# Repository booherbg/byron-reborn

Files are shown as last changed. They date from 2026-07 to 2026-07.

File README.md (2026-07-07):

# Byron Reborn

A fully 3D-printed, genuinely leak-proof replacement lid for the **Contigo Byron 2.0** 16oz travel mug (SnapSeal style) — because the OEM lid warps eventually, and the mug deserves better.

**Status:** toolkit built (measuring kit + thread test rings in `stl/`). Waiting on mug
measurements — **see [NEXT-STEPS.md](NEXT-STEPS.md) to pick this up** (30-min human
checklist + a paste-ready LLM resume prompt).

## The idea

- **Parametric OpenSCAD** (BOSL2 threads) — every mug measurement is a variable in `scad/params.scad`
- **Main seal, two variants:** a gland for the OEM Byron silicone grommet (daily driver), and a 100%-printed double-lip skirt (the experiment)
- **Snap lever spout:** an over-center lever cams a hollow tapered plug into a printed taper seat — Luer-fitting physics, no o-rings
- **Printed metrology:** no calipers? The printer bootstraps its own measuring kit (step-cone bore gauge, thread pitch comb, grommet slot card)
- **PETG only** — coffee is hotter than PLA's glass transition; that heat creep is what killed the original lid

Full design: [docs/superpowers/specs/2026-07-07-byron-lid-design.md](docs/superpowers/specs/2026-07-07-byron-lid-design.md)

## Hardware

- Contigo Byron **2.0** 16oz (the newer AUTOSEAL tops use a different interface — this won't fit those)
- Bambu Lab H2D, PETG

## Safety notes

Hobby part, not NSF-certified. Hand-wash only, reprint periodically, PETG throughout.

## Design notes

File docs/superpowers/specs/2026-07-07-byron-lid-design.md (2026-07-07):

# Byron Reborn — Printed Leak-Proof Replacement Lid for Contigo Byron 2.0 (16oz)

**Date:** 2026-07-07
**Status:** Approved (design review with Blaine, this date)
**Target hardware:** Contigo Byron 2.0 Stainless Steel Travel Mug, SnapSeal lid style, 16oz (SAP_2100871). The Byron 2.0 specifically — not the AUTOSEAL/West Loop family, whose published 3D models do not fit this mug.
**Printer/materials:** Bambu Lab H2D; PETG for all parts (PLA is excluded for anything that touches heat: Tg ≈ 60 °C vs. 80–90 °C coffee — heat creep is what warped the original lid). Hand-wash only.

## 1. Goal and success criteria

Replace the warped, leaking OEM SnapSeal lid with a printed lid that restores true leak-proofness. The lid passes when it:

1. Holds an 85 °C fill inverted overnight with no visible drop on a paper towel (room-temp phase).
2. Survives 2 hours on its side in a packed backpack after a hot fill, dry.
3. Still passes both after 5 hot fill/cool cycles (creep check) and 200 lever open/close cycles.
4. Opens and closes one-handed with a thumb (snap-open, snap-shut, audible/tactile detent).
5. Uses at most: printed parts + one OEM Byron grommet (spares on hand). No glue, no metal hardware, no purchased o-rings.

Non-goals: dishwasher survival (v3 candidate in polycarbonate), NSF/food certification, fitting any other Contigo model.

## 2. Architecture

Three printed pieces plus the optional grommet:

1. **Lid body** — threaded skirt, main-seal feature (variant-dependent), spout with integral taper seat, lever pivot bosses, detent pocket.
2. **Lever** — U-shaped over-center snap lever with cam lobe and half of the floating-plug coupling.
3. **Plug** — hollow thin-wall tapered plug; crown carries the other half of the ball-and-socket coupling.

One parametric OpenSCAD model (BOSL2 for threads) emits every part and variant. All measured values live in `scad/params.scad`; geometry files never contain magic numbers.

### 2.1 Thread interface

- Assumption (to confirm from photos before Phase 0): the lid screws **into** the stainless neck — male threads on the lid skirt engaging female thread features inside the mug rim, gasket sealing radially against the smooth bore above them, West-Loop-convention. If photos show the opposite (external threads on the neck), the model flips to a female-threaded cap skirt; BOSL2 supports both and the rest of the design is unchanged.
- Expected form: coarse trapezoidal/buttress-ish profile, **multi-start (likely 3–4)**. Measured fact (Blaine, 2026-07-07): the OEM lid removes in **exactly one half turn**, so usable thread length ≈ lead/2 — with a plausible 3–4 mm pitch that implies a lead around 12–16 mm and a thread band ~6–8 mm tall. Thread starts = count of thread entry points visible around the rim; photos confirm starts and pitch, and measured lead must satisfy the half-turn constraint.
- Parameters: `thread_d`, `lead`, `starts`, `thread_depth`, `thread_len`, `radial_clearance`.
- Fit strategy: print **thread-fit rings** (thread band only, ~15 min each) at radial clearances 0.15 / 0.30 / 0.45 mm, embossed labels. Pass = spins on smoothly, seats with no wobble. Winning numbers freeze into `params.scad`.

### 2.2 Main seal (two variants, one boolean)

- **Variant G — grommet gland (daily driver):** circumferential groove in the lid body sized to the measured grommet cross-section at ~20% compression, with gland volume ~110–125% of the grommet's cross-section volume so the seal fills only ~80–90% of the groove when compressed (rubber is incompressible; it needs somewhere to go). The lid is a rigid, round carrier for the seal Contigo engineered for this bore — highest-confidence path, immune to PETG creep.
- **Variant L — printed double-lip skirt (pure-print experiment):** two concentric conical PETG skirts, ~0.9 mm wall, free diameter ~1.2 mm over bore diameter, ~35° flare, deflecting inward against the bore as the lid tightens. Second lip = labyrinth redundancy. Known risk: stress relaxation at coffee temperature over weeks; acceptable because reprints are free and Variant G is the daily driver.

### 2.3 Spout and snap-lever mechanism

- **Seat:** Ø ≈ 17 mm drink opening (matches OEM feel; wide enough to gulp-vent, so no separate vent hole exists to leak), taper ≈ 1:6, formed as a thin (~1.2 mm) inner sleeve so seat and plug share compliance.
- **Plug:** hollow cone, ~1.2 mm wall, printed vertically so the sealing band is continuous perimeter wall (FDM's smoothest surface). Luer-fitting principle: taper self-centers and seals plastic-on-plastic; thin wall adds collet-like radial give.
- **Floating coupling:** plug hangs from the lever cam via a loose printed ball-and-socket. The cam pushes purely axially; the taper centers the plug. A rigid connection would drag the plug sideways along the lever arc and score the seat — this coupling is load-bearing for sealing, not a flourish.
- **Lever:** pivots on side bosses; over-center geometry (closed position ~2–3° past peak cam force) plus a detent bump so closed is a stable snap, not a friction hope. Cam leverage also cracks the vacuum of cooled coffee with a thumb-flick. Cooling vacuum pulls the plug tighter — the in-bag scenario is the cooling phase, which works in our favor.
- **Hinge, two interchangeable builds:** (a) print-in-place pin, (b) two-piece snap-pin — same interfaces, PETG print-in-place tolerance decides the winner.
- **Fallback (agreed):** the seat also accepts a small threaded **screw-plug** cap — if the lever fights us, pivoting is one print, not a redesign.

## 3. Measurement plan (Phase –1)

No calipers on hand; the printer bootstraps its own metrology (~25 min of printing), backed by ruler photos.

**Printed measuring kit:**
- **Step-cone gauge** — drops into the mug mouth; labeled 1 mm steps; the step it lands on reads the bore Ø to ±0.3 mm (a finer 0.5 mm-step follow-up cone narrows it further if needed).
- **Pitch comb** — tooth sets at candidate pitches held against the neck threads; the set that nests is the pitch/lead.
- **Slot gauge card** — stepped slots (2.0–6.0 mm × 0.25) to read the grommet cross-section; soft rubber measures badly under a ruler, well in a slot.

**Photo shot list (Blaine, ruler in frame):**
1. Top-down of the mug mouth, ruler across the diameter.
2. Side closeup of neck threads, ruler vertical.
3. Rim shot for counting thread entry points (starts).
4. Turns to seat the old lid — **answered: exactly ½ turn** (recorded above; constrains lead × thread length).
5. Old lid: side profile; underside with grommet removed; mechanism open (side + below) — the OEM lid is the proportion reference for lever/cam geometry.
6. Grommet flat on the ruler (OD) and pinched against it (cross-section sanity check vs. slot gauge).

## 4. Print recipe (watertightness is also a slicer problem)

- PETG everywhere; H2D, 0.4 mm nozzle.
- Body/lever: 0.20 mm layers, 4 perimeters, ~40% gyroid infill, 5 top/bottom layers.
- Plug + seat region + lip skirts: 0.12 mm layers, ~103% flow (perimeter fusion over dimensional vanity).
- Scarf seams on; paint seams away from every sealing surface; sealing faces oriented as vertical walls; no supports touching any sealing face (plug prints standalone, cone-up).
- Body watertightness check before any mechanism work: fill with water, watch for weep at 10 min.
- If a taper interface weeps after bedding-in: 60 s of toothpaste lapping (plug twisted in seat), rinse thoroughly.

## 5. Test ladder (every rung is a sub-hour print)

| Phase | Article | Pass gate |
|---|---|---|
| –1 | Measuring kit | Numbers recorded in `params.scad` |
| 0 | Thread rings ×3 clearances | Smooth engage, no wobble, full seat |
| 1 | Blank sealed disc, Variant G | Criteria 1–2, plus retest after 5 hot cycles (no lever exists yet) |
| 2 | Blank disc, Variant L | Same gates as Phase 1; result decides L's fate |
| 3 | Full lid, lever + plug (both hinge builds) | All success criteria 1–5 |
| 4 | Daily-driver soak: one work week of real use | No regressions; log in `prints.md` |

## 6. Risks and honest limits

| Risk | Mitigation |
|---|---|
| PETG stress relaxation at 85 °C (lip variant relaxes over weeks) | Variant G daily driver; reprints are free consumables |
| Taper plug sticks after hot cycle | Taper angle parameter (shallower = more force, stickier); paraffin/food wax; cam leverage sized to crack it |
| PETG print-in-place hinge fuses or rattles | Two-piece snap-pin build of the same lever |
| Thread assumption wrong (external vs. internal) | Resolved by photos before any Phase-0 print; model flips parametrically |
| FDM crevices harbor coffee residue | Hand-wash, periodic reprint; stated non-goal: food certification |
| Grommet cross-section measured wrong | Slot gauge + 20% compression window is forgiving; gland depth is one parameter |

## 7. Project layout & workflow

```
2026-coffee-lid/
  docs/superpowers/specs/   this document
  scad/                     lid.scad + params.scad (BOSL2)
  stl/                      exported per-part STLs
  renders/                  CLI-rendered previews (PNG / web view) per design change
  prints.md                 print + test log (what printed, settings, result)
```

Iteration loop: edit `params.scad` → `openscad` CLI renders previews (Blaine reviews images/web view, no CAD app needed) → export STL → Bambu Studio slice → print → log result → adjust parameters. BOSL2 is a one-time `git clone` into the OpenSCAD library path.

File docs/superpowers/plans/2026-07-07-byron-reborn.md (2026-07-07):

# Byron Reborn Implementation Plan

> **For agentic workers:** REQUIRED SUB-SKILL: Use superpowers:subagent-driven-development (recommended) or superpowers:executing-plans to implement this plan task-by-task. Steps use checkbox (`- [ ]`) syntax for tracking.

**Goal:** A fully printed, parametric, leak-proof PETG replacement lid (snap-lever, SnapSeal-style) for the Contigo Byron 2.0 16oz mug, plus the printed metrology and test articles that get us there.

**Architecture:** One OpenSCAD parameter file (`scad/params.scad`) is the single source of truth; geometry files (`gauges`, `ring`, `lid`, `mech`, `full_lid`, `assembly`) consume it and emit parts selected by a `PART` variable. A Makefile drives check (headless render with asserts), PNG previews, an HTML gallery, and STL export. Physical reality enters through explicit **PRINT GATES** (Blaine prints/measures; results freeze `[PROVISIONAL]` parameters to `[MEASURED]`).

**Tech Stack:** OpenSCAD CLI (Homebrew), BOSL2 (git submodule, pinned), GNU make, Bambu Studio (slicing only), git/GitHub (`booherbg/byron-reborn`, branch `master`).

## Global Constraints

- Target hardware: Contigo Byron 2.0 **16oz** SnapSeal (SAP_2100871) only.
- Material: **PETG** for every part that touches heat or seals. PLA allowed only for the measuring kit (Task 4–6) — gauges never touch hot water.
- Half-turn law (measured 2026-07-07): OEM lid removes in exactly ½ turn ⇒ `thread_len` must stay within `[0.35, 0.55] × lead` (asserted in code).
- Sealing faces print as vertical perimeter walls; no supports and no seam on any sealing face.
- All numbers live in `scad/params.scad` with `[MEASURED]`/`[PROVISIONAL]` status tags; geometry files contain **no magic numbers**.
- Every part passes `make check` before STL export; STLs and renders are committed (maker repo — people download STLs).
- OpenSCAD syntax compatible with 2021.01; BOSL2 pinned as a submodule (exact hash recorded by git).
- No glue, no metal hardware, no purchased o-rings; at most one OEM Byron grommet.
- Commit after every green step. PRINT GATE steps require Blaine and end the autonomous run until results arrive.

## File Map

```
Makefile                 build driver: check / renders / gallery / stl
prints.md                print + physical test log (append-only table)
scad/lib/BOSL2/          submodule (threads library)
scad/params.scad         ALL parameters + derived values + asserts
scad/smoke.scad          toolchain + BOSL2 + params sanity article
scad/gauges.scad         PART = "cone" | "comb" | "slotcard"
scad/ring.scad           thread-fit test ring (clearance from CLR variable)
scad/lid.scad            lid body; VARIANT = "G"|"L", SPOUT = true|false
scad/mech.scad           PART = "plug" | "lever" | "pin" | "screwplug"
scad/full_lid.scad       lid + mech combined (HINGE = "pin"|"pip")
scad/assembly.scad       render-only scenes: closed cutaway / open / exploded
tools/gallery.sh         renders/*.png → renders/index.html
docs/photos/             Blaine drops mug/lid photos here (Task 9)
stl/  renders/  build/   outputs (build/ is gitignored)
```

Tasks 1–8 are photo-independent (do today). Tasks 9–18 gate on photos/prints.

---

### Task 1: Scaffolding, Makefile, print log

**Files:**
- Create: `Makefile`, `prints.md`, `.gitignore`, `scad/`, `tools/`, `docs/photos/.gitkeep`

**Interfaces:**
- Produces: `make check` / `make renders` / `make gallery` / `make stl` targets; `build/` for intermediates; part lists via `PARTS_*` variables consumed by later tasks as they add parts.

- [x] **Step 1: Record toolchain versions (the "failing test" is: Makefile doesn't exist yet)**

Run: `openscad --version 2>&1; make --version | head -1`
Expected: OpenSCAD version prints (2021.01 or newer). Record the exact string in `prints.md` header (Step 3). `make check` fails with "No rule" — that's the red state.

- [x] **Step 2: Write `Makefile`**

```make
OPENSCAD ?= openscad
SCAD_FLAGS := --hardwarnings
RENDER_FLAGS := --imgsize 1100,850 --autocenter --viewall --projection p
comma := ,

# Geometry files added as tasks land. Each must render standalone with asserts passing.
CHECK_SRCS := scad/smoke.scad
# name:file:defines  (defines comma-separated, empty allowed)
PARTS :=

.PHONY: check renders gallery stl clean
check: $(patsubst scad/%.scad,build/%.echo,$(CHECK_SRCS))
build/%.echo: scad/%.scad scad/params.scad | build
	$(OPENSCAD) $(SCAD_FLAGS) -o $@ $<
	@echo "OK $<"

# Expand PARTS into render + stl rules
define PART_template
renders/$(1).png: scad/$(2) scad/params.scad | renders
	$$(OPENSCAD) $$(SCAD_FLAGS) $$(RENDER_FLAGS) $(3) -o $$@ $$<
stl/$(1).stl: scad/$(2) scad/params.scad | stl
	$$(OPENSCAD) $$(SCAD_FLAGS) $(3) -o $$@ $$<
RENDER_TARGETS += renders/$(1).png
STL_TARGETS += stl/$(1).stl
endef
$(foreach p,$(PARTS),$(eval $(call PART_template,$(word 1,$(subst :, ,$(p))),$(word 2,$(subst :, ,$(p))),$(subst $(comma), ,$(word 3,$(subst :, ,$(p)))))))

renders: $(RENDER_TARGETS)
	./tools/gallery.sh
gallery: renders
stl: $(STL_TARGETS)
build renders stl:
	mkdir -p $@
clean:
	rm -rf build
```

Note: `PARTS` entries look like `gauge-cone:gauges.scad:-DPART=\"cone\"` — added by later tasks. Three rules: the template quoting (`$$`) is required inside `define`; string defines need `\"` escapes so the shell delivers real quotes to OpenSCAD (`-DPART=cone` without them is an undefined *variable*, not a string); multiple defines in the third field are separated by commas, which the foreach converts to spaces (a raw space would split the entry into two PARTS words).

- [x] **Step 3: Write `prints.md`**

```markdown
# Print & Test Log — Byron Reborn

Toolchain: OpenSCAD <paste `openscad --version` here>, Bambu Studio, H2D, 0.4mm nozzle.

| Date | Part (stl @ commit) | Filament | Key settings | Result | Notes |
|---|---|---|---|---|---|
```

- [x] **Step 4: Write `.gitignore`**

```
build/
.DS_Store
```

- [x] **Step 5: Verify green, commit**

Run: `mkdir -p scad tools docs/photos && touch docs/photos/.gitkeep && make check`
Expected: FAIL — "No rule to make target 'scad/smoke.scad'" (red until Task 2). Commit anyway — scaffolding is the deliverable:
```bash
git add Makefile prints.md .gitignore docs/photos/.gitkeep && git commit -m "build: scaffolding, Makefile part-template, print log"
```

### Task 2: BOSL2 submodule + smoke article

**Files:**
- Create: `scad/lib/BOSL2` (submodule), `scad/smoke.scad`
- Modify: `Makefile` (nothing — smoke.scad already in CHECK_SRCS)

**Interfaces:**
- Produces: `include <lib/BOSL2/std.scad>` + `include <lib/BOSL2/threading.scad>` usable from any `scad/*.scad`; smoke part proves multi-start threads render.

- [x] **Step 1: Red — `make check` fails (smoke.scad missing)**

Run: `make check` — Expected: "No rule to make target" mentioning smoke.

- [x] **Step 2: Add submodule**

```bash
git submodule add https://github.com/BelfrySCAD/BOSL2.git scad/lib/BOSL2
```

- [x] **Step 3: Write `scad/smoke.scad`** (threads + params echo in one sanity article; params.scad arrives in Task 3 — for now create it as an empty file so includes resolve)

```bash
touch scad/params.scad
```

```openscad
// smoke.scad — toolchain sanity: BOSL2 loads, multi-start thread renders, params parse.
include <params.scad>
include <lib/BOSL2/std.scad>
include <lib/BOSL2/threading.scad>
$fn = 64;
trapezoidal_threaded_rod(d=20, l=10, pitch=4, thread_angle=30, starts=4, blunt_start=true);
echo("SMOKE_OK");
```

- [x] **Step 4: Green**

Run: `make check`
Expected: output contains `ECHO: "SMOKE_OK"` and `OK scad/smoke.scad`, exit 0. (If `blunt_start` is unknown in the pinned BOSL2, delete that argument — it's cosmetic here.)

- [x] **Step 5: Commit**

```bash
git add .gitmodules scad/lib/BOSL2 scad/smoke.scad scad/params.scad && git commit -m "build: BOSL2 submodule + thread smoke test"
```

### Task 3: params.scad — single source of truth

**Files:**
- Modify: `scad/params.scad` (replace empty file), `scad/smoke.scad` (echo the report)

**Interfaces:**
- Produces (exact names later tasks consume): `bore_d, bore_depth, rim_od, thread_pitch, thread_starts, thread_d, thread_depth, thread_angle, thread_len, thread_clearance, lead, grommet_cs_w, grommet_cs_h, grommet_od, gland_compression, gland_floor_d, gland_w, lip_wall, lip_flare_deg, lip_oversize, lip_h, lip_gap, skirt_wall, top_th, flange_d, flange_th, seat_top_d, seat_bot_d, seat_h, seat_wall, seat_taper, plug_wall, plug_fit_gap, stem_d, stem_h, head_d, lever_w, lever_arm_t, pivot_d, pip_gap, pin_press, cam_lift, overcenter_deg, detent_r, spout_ext_thread_p, spout_ext_thread_d, fdm_xy_comp` — all in mm/deg.

- [x] **Step 1: Red — write the assert first.** Append to `scad/smoke.scad`:

```openscad
assert(!is_undef(lead), "params.scad must define lead");
echo(str("PARAMS: bore_d=", bore_d, " lead=", lead, " thread_len=", thread_len,
         " gland_floor_d=", gland_floor_d, " seat: ", seat_bot_d, "→", seat_top_d, "x", seat_h));
```

Run: `make check` — Expected: FAIL, `lead` undefined.

- [x] **Step 2: Write `scad/params.scad`**

```openscad
// ============ Byron Reborn — ALL parameters ============
// Status tags: [MEASURED] = confirmed by gauge/photo/print; [PROVISIONAL] = plausible default.
// Phase -1/0 (Tasks 9-10) flips mug-interface tags to [MEASURED]. Geometry files: NO magic numbers.

// ---- Mug interface (assumption to confirm: lid threads INTO neck, male-on-lid) ----
bore_d        = 54.0;   // [PROVISIONAL] smooth sealing bore Ø above threads (step-cone gauge)
bore_depth    = 10.0;   // [PROVISIONAL] rim to gasket-seat depth
rim_od        = 60.0;   // [PROVISIONAL] outer rim Ø (flange overhangs this)
thread_pitch  = 4.0;    // [PROVISIONAL] crest-to-crest, pitch comb
thread_starts = 4;      // [PROVISIONAL] entry points counted on rim photo
thread_d      = 57.0;   // [PROVISIONAL] male thread major Ø on lid
thread_depth  = 1.6;    // [PROVISIONAL] radial depth
thread_angle  = 30;     // [PROVISIONAL] flank angle (trapezoidal)
thread_len    = 7.0;    // [PROVISIONAL] axial thread band
thread_clearance = 0.30;// [PROVISIONAL→Phase 0 winner] radial, applied to male Øs
lead = thread_pitch * thread_starts;
// Half-turn law (measured 2026-07-07): full disengage in exactly 0.5 turn.
assert(thread_len >= 0.35*lead && thread_len <= 0.55*lead,
  str("thread_len ", thread_len, " violates half-turn law vs lead ", lead));

// ---- Variant G: OEM grommet gland (radial squeeze between gland floor and bore) ----
grommet_cs_w = 3.5;     // [PROVISIONAL] radial cross-section (slot card)
grommet_cs_h = 4.5;     // [PROVISIONAL] axial cross-section
grommet_od   = 56.0;    // [PROVISIONAL] free outer Ø (ruler photo)
gland_compression = 0.20;         // radial squeeze fraction
gland_floor_d = bore_d - 2*grommet_cs_w*(1-gland_compression);
gland_w = grommet_cs_h * 1.18;    // axial room: rubber is incompressible, needs somewhere to go
// gland fill sanity (rounded cross-section factor 0.9): target ≤ ~90%
gland_fill = (grommet_cs_w*grommet_cs_h*0.9) / (((bore_d-gland_floor_d)/2)*gland_w);
assert(gland_fill > 0.65 && gland_fill < 0.92, str("gland fill ", gland_fill));

// ---- Variant L: printed double-lip skirt ----
lip_wall = 0.9; lip_flare_deg = 35; lip_oversize = 1.2; lip_h = 4.0; lip_gap = 3.0;

// ---- Body ----
skirt_wall = 2.4; top_th = 2.8; flange_th = 3.0;
flange_d = rim_od + 4;            // overhangs rim by 2mm/side
fdm_xy_comp = 0.0;                // slicer handles XY comp; keep 0 in CAD

// ---- Spout seat (shared by lever plug AND screw-plug fallback) ----
seat_top_d = 17.8; seat_bot_d = 16.8; seat_h = 6.0; seat_wall = 1.2;
seat_taper = (seat_top_d - seat_bot_d) / (2*seat_h);   // ≈1:12 per side = 1:6 on Ø
plug_wall = 1.2; plug_fit_gap = 0.05;   // per-side; lapping closes the rest
stem_d = 3.5; stem_h = 8.0; head_d = 6.0;

// ---- Lever / hinge / detent ----
lever_w = 14; lever_arm_t = 6; pivot_d = 4.0;
pip_gap = 0.35;                    // print-in-place radial gap
pin_press = 0.10;                  // snap-pin: press fit in lever, free in boss
cam_lift = 2.5;                    // plug travel open→closed
overcenter_deg = 3;                // closed sits past peak force
detent_r = 1.0;

// ---- Screw-plug fallback (external thread on seat sleeve) ----
spout_ext_thread_p = 2.5; spout_ext_thread_d = 21.5;
```

- [x] **Step 3: Green**

Run: `make check`
Expected: `ECHO: "PARAMS: bore_d=54 lead=16 thread_len=7 gland_floor_d=48.4 seat: 16.8→17.8x6"`, exit 0.

- [x] **Step 4: Commit**

```bash
git add scad/params.scad scad/smoke.scad && git commit -m "feat: full parameter set with half-turn + gland-fill asserts"
```

### Task 4: Step-cone bore gauge

**Files:**
- Create: `scad/gauges.scad`
- Modify: `Makefile` (CHECK_SRCS += gauges.scad; PARTS += cone entry)

**Interfaces:**
- Produces: `module step_cone_gauge()`; part id `gauge-cone`; `PART` selector convention (`PART="all"` default renders everything in the file, specific name exports one part).

- [x] **Step 1: Red.** Makefile: `CHECK_SRCS := scad/smoke.scad scad/gauges.scad` and `PARTS += gauge-cone:gauges.scad:-DPART=\"cone\"`. Run `make check` — Expected: FAIL (gauges.scad missing).

- [x] **Step 2: Write `scad/gauges.scad`**

```openscad
// gauges.scad — printed metrology (PLA fine: never touches heat)
include <params.scad>
PART = "all";
$fn = 128;
FONT = "Liberation Sans:style=Bold";

// Step cone: largest step on bed, stack shrinks upward => no overhang.
// In use: flip tip-down into mug mouth; the step that rests on the rim = bore Ø.
module step_cone_gauge(d_min=44, d_max=62, step=1, h_step=4) {
  n = floor((d_max - d_min)/step);
  difference() {
    union() {
      for (i=[0:n]) {
        d = d_max - i*step;
        translate([0,0,i*h_step]) cylinder(d=d, h=h_step+0.02);
        // embossed label on the step wall, 0.5mm proud
        translate([0,0,i*h_step + h_step/2]) label_on_wall(d, str(d));
      }
      translate([0,0,(n+1)*h_step - 0.01]) grip_bar(d_max - n*step);
    }
    translate([0,0,-1]) cylinder(d=10, h=(n+2)*h_step); // finger/retrieval bore
  }
}
module label_on_wall(d, txt)
  rotate([0,0,0]) translate([d/2 - 0.1, 0, 0]) rotate([90,0,90])
    linear_extrude(0.6) text(txt, size=2.6, font=FONT, halign="center", valign="center");
module grip_bar(d_top)
  translate([-d_top/2, -4, 0]) cube([d_top, 8, 6]);

if (PART=="cone" || PART=="all") step_cone_gauge();
echo("GAUGES_OK");
```

- [x] **Step 3: Green + render**

Run: `make check && make renders/gauge-cone.png stl/gauge-cone.stl`
Expected: check echoes `GAUGES_OK`; PNG and STL exist. Open the PNG: 19 shrinking steps, labels visible, grip bar on top, Ø10 bore through.

- [x] **Step 4: Commit**

```bash
git add scad/gauges.scad Makefile renders/gauge-cone.png stl/gauge-cone.stl && git commit -m "feat: step-cone bore gauge (44-62mm, 1mm steps)"
```

### Task 5: Thread pitch comb

**Files:**
- Modify: `scad/gauges.scad`, `Makefile` (PARTS += `gauge-comb:gauges.scad:-DPART=\"comb\"`)

**Interfaces:**
- Produces: `module pitch_comb()`; part id `gauge-comb`. Candidate pitches `[2,2.5,3,3.5,4,4.5,5,6]` — 4 per long edge of one card.

- [x] **Step 1: Red.** Add to `gauges.scad`: `if (PART=="comb" || PART=="all") translate([80,0,0]) pitch_comb();` before writing the module. `make check` — Expected: FAIL "unknown module pitch_comb".

- [x] **Step 2: Implement**

```openscad
// Hold a comb edge against the neck threads; the tooth set that nests IS the pitch.
module pitch_comb(pitches=[2,2.5,3,3.5,4,4.5,5,6], seg=22, card=[100,42,2.4]) {
  difference() {
    union() {
      cube(card);
      for (i=[0:3]) comb_edge(pitches[i],   [4 + i*(seg+3), card[1], 0], 0);      // top edge
      for (i=[0:3]) comb_edge(pitches[i+4], [4 + i*(seg+3) + seg, 0, 0], 180);    // bottom edge
    }
    for (i=[0:3]) label(pitches[i],   [4 + i*(seg+3) + seg/2, card[1]-6]);
    for (i=[0:3]) label(pitches[i+4], [4 + i*(seg+3) + seg/2, 6]);
  }
}
module comb_edge(p, at, rot) translate(at) rotate([0,0,rot]) {
  n = floor(22/p);
  for (t=[0:n-1]) translate([t*p, 0, 0])
    linear_extrude(2.4) polygon([[0,0],[p/2,2.5],[p,0]]);  // 2.5mm-deep V teeth at pitch p
}
module label(p, at) translate([at[0], at[1], 2.4-0.6])
  linear_extrude(0.7) text(str(p), size=4, font=FONT, halign="center", valign="center");
```

- [x] **Step 3: Green + render.** Run: `make check && make renders/gauge-comb.png stl/gauge-comb.stl` — Expected: card with 8 labeled comb edges, teeth pointing outward from both long edges.

- [x] **Step 4: Commit**

```bash
git add scad/gauges.scad Makefile renders/gauge-comb.png stl/gauge-comb.stl && git commit -m "feat: thread pitch comb (2-6mm, 8 candidates)"
```

### Task 6: Grommet slot card

**Files:**
- Modify: `scad/gauges.scad`, `Makefile` (PARTS += `gauge-slotcard:gauges.scad:-DPART=\"slotcard\"`)

**Interfaces:**
- Produces: `module slot_card()`; part id `gauge-slotcard`. Slots 2.00–6.00mm × 0.25 steps, two rows; grommet cross-section slides in until snug — snug slot = cross-section dimension.

- [x] **Step 1: Red.** Add `if (PART=="slotcard" || PART=="all") translate([0,-70,0]) slot_card();` — `make check` fails on unknown module.

- [x] **Step 2: Implement**

```openscad
module slot_card(w_min=2.0, w_max=6.0, step=0.25, depth=11, th=3.0, wall=3.2) {
  ws = [for (w=[w_min:step:w_max]) w];
  half = ceil(len(ws)/2);
  row1 = [for (i=[0:half-1]) ws[i]]; row2 = [for (i=[half:len(ws)-1]) ws[i]];
  cardw = max(row_len(row1,wall), row_len(row2,wall)) + 2*wall;
  difference() {
    cube([cardw, 2*depth + 18, th]);
    slot_row(row1, wall, 0,               depth, th);          // slots from bottom edge
    slot_row(row2, wall, 2*depth + 18,    -depth, th);         // slots from top edge (mirrored)
    for (r=[0,1]) for (i=[0:len(r==0?row1:row2)-1])
      let(w = (r==0?row1:row2)[i], x = slot_x(r==0?row1:row2, i, wall))
      translate([x + w/2, r==0 ? depth+4 : depth+14, th-0.6])
        linear_extrude(0.7) text(str(w), size=2.8, font=FONT, halign="center");
  }
}
function row_len(row, wall) = len(row)==0 ? 0 :
  wall + sum_up(row, len(row)-1) + len(row)*wall;
function sum_up(v, i) = i<0 ? 0 : v[i] + sum_up(v, i-1);
function slot_x(row, i, wall) = wall + sum_up(row, i-1) + i*wall + wall;
module slot_row(row, wall, y0, depth, th)
  for (i=[0:len(row)-1])
    translate([slot_x(row,i,wall), depth>0 ? y0-0.5 : y0-depth-0.5+depth, -0.5])
      cube([row[i], abs(depth)+0.5, th+1]);
```

Note: the two `slot_row` translate branches must both start the cut at the card edge (`y0` for bottom row, `y0-|depth|` for top row); the expression above collapses to that — verify visually in the render (Step 3), it's the step most likely to need a sign fix.

- [x] **Step 3: Green + render.** Run: `make check && make renders/gauge-slotcard.png stl/gauge-slotcard.stl` — Expected: one card, 17 labeled slots in two opposing rows, all cuts reaching their edge.

- [x] **Step 4: Commit**

```bash
git add scad/gauges.scad Makefile renders/gauge-slotcard.png stl/gauge-slotcard.stl && git commit -m "feat: grommet slot gauge card (2-6mm x 0.25)"
```

### Task 7: Thread test-ring generator

**Files:**
- Create: `scad/ring.scad`
- Modify: `Makefile` (CHECK_SRCS += ring.scad; PARTS += `ring-c15:ring.scad:-DCLR=0.15`, `ring-c30:ring.scad:-DCLR=0.30`, `ring-c45:ring.scad:-DCLR=0.45`)

**Interfaces:**
- Consumes: all `thread_*`, `lead` from params.
- Produces: `module test_ring(clr)`; STLs `ring-c15/30/45.stl`; embossed label format `C<clr*100> P<pitch> S<starts>` so printed rings stay identifiable.

- [x] **Step 1: Red.** Update Makefile lists; `make check` fails (ring.scad missing).

- [x] **Step 2: Write `scad/ring.scad`**

```openscad
// ring.scad — 15-minute thread-fit coupon. Print 3 clearances; the one that spins
// smoothly and seats without wobble wins; its CLR freezes into params.thread_clearance.
include <params.scad>
include <lib/BOSL2/std.scad>
include <lib/BOSL2/threading.scad>
CLR = 0.30;
$fn = 96;
module test_ring(clr=CLR) {
  grip_d = thread_d + 9;
  difference() {
    union() {
      cylinder(d=grip_d, h=2);                                  // base flange
      translate([0,0,2]) trapezoidal_threaded_rod(
        d=thread_d - 2*clr, l=thread_len, pitch=thread_pitch,
        thread_angle=thread_angle, starts=thread_starts,
        blunt_start=true, anchor=BOTTOM);
      for (a=[0:15:345]) rotate([0,0,a])                        // grip fins on the flange
        translate([grip_d/2-1.5, -1, 0]) cube([3, 2, 2]);
    }
    translate([0,0,-0.5]) cylinder(d=thread_d - 2*thread_depth - 2*clr - 2*skirt_wall,
                                   h=thread_len + 3);           // hollow center
    translate([0, 0, 0.4]) rotate([0,0,0]) label_bottom(clr);
  }
}
module label_bottom(clr) mirror([1,0,0]) translate([0,-(thread_d/2+2),-0.45])
  linear_extrude(0.5) text(str("C", clr*100, " P", thread_pitch, " S", thread_starts),
                           size=3.5, font="Liberation Sans:style=Bold", halign="center");
test_ring();
echo(str("RING_OK clr=", CLR));
```

- [x] **Step 3: Green + renders/STLs.** Run: `make check && make renders stl`
Expected: `RING_OK` ×1 in check; `ring-c15/30/45` PNGs + STLs; label readable (mirrored text on the underside prints readable from below).

- [x] **Step 4: Commit**

```bash
git add scad/ring.scad Makefile renders/ring-*.png stl/ring-*.stl && git commit -m "feat: parametric thread test rings at 3 clearances"
```

### Task 8: Render gallery (the "web view")

**Files:**
- Create: `tools/gallery.sh`

**Interfaces:**
- Produces: `renders/index.html` — static, self-contained gallery of every PNG; regenerated by `make renders`.

- [x] **Step 1: Red.** Run: `make renders` — Expected: FAIL at `./tools/gallery.sh` (missing).

- [x] **Step 2: Write `tools/gallery.sh`**

```bash
#!/bin/sh
# Static preview gallery: renders/index.html
set -e
out=renders/index.html
{
  echo '<!doctype html><meta charset="utf-8"><title>Byron Reborn previews</title>'
  echo '<style>body{font-family:system-ui;background:#111;color:#eee;margin:2rem}'
  echo 'figure{display:inline-block;margin:1rem;text-align:center}img{max-width:340px;border-radius:8px;background:#fff}</style>'
  echo "<h1>Byron Reborn — $(git rev-parse --short HEAD 2>/dev/null || echo dev)</h1>"
  for f in renders/*.png; do
    b=$(basename "$f")
    echo "<figure><img src=\"$b\" alt=\"$b\"><figcaption>$b</figcaption></figure>"
  done
} > "$out"
echo "gallery: $out"
```

- [x] **Step 3: Green.** Run: `chmod +x tools/gallery.sh && make renders && open renders/index.html`
Expected: browser shows every part render with captions.

- [x] **Step 4: Commit**

```bash
git add tools/gallery.sh renders/index.html && git commit -m "feat: static render gallery for web previews"
```

### Task 9: PRINT GATE — measuring kit + photos ⇒ measured params

**Files:**
- Modify: `scad/params.scad` (values + `[PROVISIONAL]`→`[MEASURED]` tags), `prints.md`, `docs/photos/*`

**Interfaces:**
- Consumes: `stl/gauge-*.stl` (Blaine prints; PLA fine), photo shot list from spec §3.
- Produces: `[MEASURED]` values for `bore_d, bore_depth, rim_od, thread_pitch, thread_starts, thread_d, thread_depth, thread_len, grommet_cs_w, grommet_cs_h, grommet_od`; confirmed thread handedness + male/female assumption.

- [ ] **Step 1 (Blaine): print `gauge-cone`, `gauge-comb`, `gauge-slotcard`; take spec §3 photos into `docs/photos/`; drop gauge readings in chat or a `docs/photos/readings.txt`.**
- [ ] **Step 2: read photos (Read tool on each image), cross-check gauge readings vs photo ruler estimates; verify half-turn law against measured `lead`; update `params.scad` values + tags; log prints in `prints.md`.**
- [ ] **Step 3: Run `make check` — asserts (half-turn, gland fill) must pass with real numbers. If the male/female thread assumption flipped: file follow-up task to invert `ring.scad`/`lid.scad` thread calls (`internal=true` variants) before Phase 0 printing.**
- [ ] **Step 4: Commit**

```bash
git add scad/params.scad prints.md docs/photos && git commit -m "data: measured mug interface from gauges + photos"
```

### Task 10: PRINT GATE — thread rings ⇒ frozen clearance

**Files:**
- Modify: `scad/params.scad` (`thread_clearance` tag→`[MEASURED]`), `prints.md`

- [ ] **Step 1: Re-export rings with measured params: `make stl` (PETG this time — same material as the real lid, clearance is material-dependent).**
- [ ] **Step 2 (Blaine): print 3 rings, try each on the mug. Winner = spins smooth, seats snug, no wobble. Report.**
- [ ] **Step 3: freeze winner into `thread_clearance`, log in `prints.md`, `make check`, commit:**

```bash
git add scad/params.scad prints.md && git commit -m "data: thread clearance frozen from ring fit test"
```

### Task 11: Lid body core (threaded skirt + blank top)

**Files:**
- Create: `scad/lid.scad`
- Modify: `Makefile` (CHECK_SRCS += lid.scad; PARTS += `lid-blank-G:lid.scad:-DVARIANT=\"G\",-DSPOUT=false` — the comma becomes a space via the foreach `$(subst $(comma), ,...)`, yielding two `-D` flags)

**Interfaces:**
- Consumes: params thread/body names (Task 3).
- Produces: `module lid_body(variant, spout)` with `VARIANT`/`SPOUT` file-level selectors; `module lid_cutaway()` for renders. Coordinate convention: z=0 at skirt bottom, +z up toward flange; lid modeled in-use orientation, **printed flange-down** (slicer flips: threads print as vertical walls, no supports).

- [ ] **Step 1: Red.** Makefile lists updated; `make check` fails (lid.scad missing).

- [ ] **Step 2: Write `scad/lid.scad`**

```openscad
// lid.scad — body: male-threaded skirt (screws INTO neck), gland or lip seal, optional spout boss.
include <params.scad>
include <lib/BOSL2/std.scad>
include <lib/BOSL2/threading.scad>
VARIANT = "G";   // "G" grommet gland | "L" printed double lip
SPOUT = false;   // false = Phase 1/2 blank sealed disc
$fn = 128;
clr = thread_clearance;
seal_band_h = max(gland_w + 3, lip_h + lip_gap + 3);
body_h = thread_len + seal_band_h + flange_th;

module lid_body(variant=VARIANT, spout=SPOUT) {
  difference() {
    union() {
      // threaded band (male, multi-start)
      trapezoidal_threaded_rod(d=thread_d-2*clr, l=thread_len, pitch=thread_pitch,
        thread_angle=thread_angle, starts=thread_starts, blunt_start=true, anchor=BOTTOM);
      // seal band riding in the smooth bore
      translate([0,0,thread_len]) cylinder(d=bore_d-2*clr-0.4, h=seal_band_h);
      // flange caps the rim
      translate([0,0,thread_len+seal_band_h]) cylinder(d=flange_d, h=flange_th);
      if (variant=="L") translate([0,0,thread_len+1]) double_lip();
    }
    // hollow interior up to the top plate
    translate([0,0,-0.5]) cylinder(d=thread_d-2*thread_depth-2*clr-2*skirt_wall,
                                   h=body_h - top_th - flange_th + 0.5);
    if (variant=="G") gland_cut();
    if (spout) spout_cut();
  }
  if (spout) seat_sleeve();
}
module gland_cut()  // circumferential groove in the seal band, open outward
  translate([0,0,thread_len + 1.5]) rotate_extrude()
    translate([gland_floor_d/2, 0]) square([ (bore_d-gland_floor_d)/2 + 1, gland_w ]);
module double_lip() for (k=[0,1]) translate([0,0,k*(lip_h+lip_gap)])
  rotate_extrude() polygon([
    [bore_d/2-2*lip_wall, 0],
    [bore_d/2 + lip_oversize/2, lip_h],
    [bore_d/2 + lip_oversize/2 - lip_wall*cos(lip_flare_deg), lip_h + lip_wall*sin(lip_flare_deg)],
    [bore_d/2-2*lip_wall - lip_wall, 0.8] ]);
module spout_cut() translate([0, bore_d/4, body_h - top_th - flange_th - 0.5])
  cylinder(d=seat_bot_d - 2*seat_wall, h=top_th + flange_th + seat_h + 2);
module seat_sleeve() translate([0, bore_d/4, body_h])
  difference() {
    cylinder(d=seat_top_d + 2*seat_wall, h=seat_h);
    translate([0,0,-0.5]) cylinder(d1=seat_bot_d, d2=seat_top_d, h=seat_h+1);
  }
module lid_cutaway() difference() { lid_body(); translate([0,-200,-1]) cube(400); }
lid_body();
echo(str("LID_OK variant=", VARIANT, " spout=", SPOUT, " body_h=", body_h));
```

- [ ] **Step 3: Green + render + STL; visual check on `renders/lid-blank-G.png`: threads at bottom, smooth seal band with gland groove, flange on top, hollow inside.**

Run: `make check && make renders stl`

- [ ] **Step 4: Commit**

```bash
git add scad/lid.scad Makefile renders/lid-blank-G.png stl/lid-blank-G.stl && git commit -m "feat: lid body core with gland variant, blank top"
```

### Task 12: PRINT GATE — Phase 1 blank disc, Variant G

**Files:**
- Modify: `prints.md`; possibly `scad/params.scad` (gland tweak loop)

- [ ] **Step 1 (Blaine): print `lid-blank-G` in PETG (0.2mm, 4 walls, 103% flow on this part, seam painted to the spout-free rear, flange-down).**
- [ ] **Step 2 (Blaine): fit grommet in gland; screw on. Protocol: body watertight check (fill lid with water 10 min — no weep) → 85°C fill, invert 5 min over sink → 2h on side in backpack → overnight inverted on paper towel → 5 hot cycles → repeat overnight test.**
- [ ] **Step 3: Log results in `prints.md`. If weep at the gland: adjust `gland_compression` (+0.03 per iteration) or `gland_w`, re-export, reprint — each loop is one parameter, one 40-min print. Spec success criteria 1–2 must pass before Task 13. Commit each loop.**

### Task 13: Variant L lip disc + PRINT GATE Phase 2

**Files:**
- Modify: `Makefile` (PARTS += `lid-blank-L:lid.scad:-DVARIANT=\"L\",-DSPOUT=false`), `prints.md`

- [ ] **Step 1: `make check && make renders stl`; verify `renders/lid-blank-L.png` shows two outward-flared lips, no gland.**
- [ ] **Step 2 (Blaine): print + run the same Phase 1 protocol.**
- [ ] **Step 3: Log. L passing = pure-print bragging rights; L weeping = it stays an experiment (spec allows this). Tune `lip_oversize` ±0.3 max two loops. Commit.**

```bash
git add Makefile prints.md renders/lid-blank-L.png stl/lid-blank-L.stl && git commit -m "feat+data: lip-seal variant and Phase 2 results"
```

### Task 14: Spout coupon — seat + plug + lapping

**Files:**
- Create: `scad/mech.scad`
- Modify: `Makefile` (CHECK_SRCS += mech.scad; PARTS += `plug:mech.scad:-DPART="plug"`, `spout-coupon:mech.scad:-DPART="coupon"`)

**Interfaces:**
- Consumes: `seat_*`, `plug_*`, `stem_*`, `head_d` params.
- Produces: `module plug()` (hollow taper cone + mushroom stem, prints cone-up standalone), `module seat_ring()` (reused by lid.scad seat_sleeve geometry), part `spout-coupon` = 50mm disc + integral seat, fillable like a funnel to test the taper seal alone before any lever exists.

- [ ] **Step 1: Red.** Makefile updated; `make check` fails.

- [ ] **Step 2: Write `scad/mech.scad`**

```openscad
// mech.scad — plug, spout coupon, lever, pins, screw-plug fallback
include <params.scad>
include <lib/BOSL2/std.scad>
include <lib/BOSL2/threading.scad>
PART = "plug";
$fn = 128;

module plug() {  // prints as-modeled: cone opening up, sealing band = vertical-ish perimeters
  difference() {
    union() {
      cylinder(d1=seat_bot_d - 2*plug_fit_gap, d2=seat_top_d - 2*plug_fit_gap, h=seat_h);
      translate([0,0,seat_h]) cylinder(d=seat_top_d + 2, h=1.6);          // crown lip (stop)
      translate([0,0,seat_h+1.6]) cylinder(d=stem_d, h=stem_h);           // stem
      translate([0,0,seat_h+1.6+stem_h]) sphere(d=head_d);                // mushroom head
    }
    translate([0,0,-0.5]) cylinder(d1=seat_bot_d - 2*plug_fit_gap - 2*plug_wall,
                                   d2=seat_top_d - 2*plug_fit_gap - 2*plug_wall,
                                   h=seat_h + 0.5);                       // hollow => radial give
  }
}
module coupon() {  // funnel: disc with the seat in the middle; fill above, watch below
  difference() {
    union() { cylinder(d=50, h=3); translate([0,0,3]) seat_sleeve_local(); }
    translate([0,0,-0.5]) cylinder(d=seat_bot_d - 2*seat_wall, h=3+1);
  }
}
module seat_sleeve_local() difference() {
  cylinder(d=seat_top_d + 2*seat_wall, h=seat_h);
  translate([0,0,-0.5]) cylinder(d1=seat_bot_d, d2=seat_top_d, h=seat_h+1);
}
if (PART=="plug") plug();
if (PART=="coupon") coupon();
echo(str("MECH_OK part=", PART));
```

- [ ] **Step 3: Green + renders/STLs; commit.**

```bash
git add scad/mech.scad Makefile renders/plug.png renders/spout-coupon.png stl/plug.stl stl/spout-coupon.stl && git commit -m "feat: taper plug + spout test coupon"
```

- [ ] **Step 4: PRINT GATE (Blaine): print coupon (PETG 0.12mm layers) + plug; press plug in by hand, fill coupon, 10 min watch. If weep: 60s toothpaste lap (twist plug in seat), rinse, retest; if still weeping, deepen taper via `seat_bot_d -= 0.2` loop. Log in `prints.md`, commit.**

### Task 15: Screw-plug fallback

**Files:**
- Modify: `scad/mech.scad` (modules `screw_plug()`, external thread on `seat_sleeve_local` behind `ext_thread` flag), `scad/lid.scad` (same flag on `seat_sleeve`), `Makefile` (PARTS += `screwplug:mech.scad:-DPART="screwplug"`)

- [ ] **Step 1: Red — add `if (PART=="screwplug") screw_plug();` first; `make check` fails.**
- [ ] **Step 2: Implement**

```openscad
module seat_ext_thread()  // add-on band around the sleeve exterior
  translate([0,0,0]) trapezoidal_threaded_rod(d=spout_ext_thread_d, l=seat_h,
    pitch=spout_ext_thread_p, thread_angle=30, starts=2, blunt_start=true, anchor=BOTTOM);
module screw_plug() {
  difference() {
    union() {
      cylinder(d=spout_ext_thread_d + 7, h=3);                             // knurled cap top
      for (a=[0:20:340]) rotate([0,0,a]) translate([spout_ext_thread_d/2+2.5,-1.2,0]) cube([2.5,2.4,3]);
      translate([0,0,3]) cylinder(d=spout_ext_thread_d + 7, h=seat_h);     // cap wall stock
    }
    translate([0,0,3+0.01]) trapezoidal_threaded_rod(d=spout_ext_thread_d, l=seat_h+1,
      pitch=spout_ext_thread_p, thread_angle=30, starts=2, internal=true,
      blunt_start=true, anchor=BOTTOM, $slop=0.25);
  }
  translate([0,0,3]) difference() {  // integral taper nose sealing in the same seat
    cylinder(d2=seat_bot_d - 2*plug_fit_gap, d1=seat_top_d - 2*plug_fit_gap, h=seat_h - 0.6);
    translate([0,0,-0.5]) cylinder(d=seat_bot_d - 2*plug_fit_gap - 2*plug_wall, h=seat_h);
  }
}
```

- [ ] **Step 3: Green + render + STL (`make check && make renders stl`); coupon gets the external thread when `-DEXT_THREAD=true` — verify a `screwplug` threads onto a re-exported coupon in the render scene. Commit.**

```bash
git add scad/mech.scad scad/lid.scad Makefile renders/screwplug.png stl/screwplug.stl && git commit -m "feat: screw-plug fallback sharing the taper seat"
```

### Task 16: Lever, hinge (both builds), detent, assembly scenes

**Files:**
- Modify: `scad/mech.scad` (modules `lever()`, `snap_pin()`), Create: `scad/full_lid.scad`, `scad/assembly.scad`
- Modify: `Makefile` (CHECK_SRCS += full_lid.scad assembly.scad; PARTS += `lever:mech.scad:-DPART=\"lever\"`, `pin:mech.scad:-DPART=\"pin\"`, `full-lid-pin:full_lid.scad:-DHINGE=\"pin\"`, `full-lid-pip:full_lid.scad:-DHINGE=\"pip\"`, `scene-closed:assembly.scad:-DSCENE=\"closed\"`, `scene-open:assembly.scad:-DSCENE=\"open\"`)

**Interfaces:**
- Consumes: `lever_*`, `pivot_d`, `pip_gap`, `pin_press`, `cam_lift`, `overcenter_deg`, `detent_r`, plug stem/head names.
- Produces: `lever(hinge)` — U-lever; underside cam ramp drives the mushroom head down `cam_lift` mm as the lever rotates 90°→0° with an over-center bump in the last `overcenter_deg`; keyhole slot admits the head at open angle. `full_lid.scad` = `lid_body(spout=true)` + pivot bosses + detent pocket (+ in-place lever when `HINGE="pip"`). `assembly.scad` = colored, cutaway scenes for the gallery only.

- [ ] **Step 1: Red.** Makefile lists updated; `make check` fails on missing modules/files.

- [ ] **Step 2: Implement lever + pin in `scad/mech.scad`**

```openscad
lever_len = flange_d * 0.72;
module lever(hinge="pin") {
  pivot_hole = hinge=="pin" ? pivot_d + 0.15 : pivot_d + 2*pip_gap;
  difference() {
    union() {
      // two arms + bridge (U shape), modeled closed/flat
      for (s=[-1,1]) translate([s*(lever_w/2 - lever_arm_t/2) - lever_arm_t/2, 0, 0])
        cube([lever_arm_t, lever_len, 5]);
      translate([-lever_w/2, lever_len-10, 0]) cube([lever_w, 10, 5]);   // thumb bridge
      cam_block();
    }
    for (s=[-1,1]) translate([s*(lever_w/2)+ (s<0?-1:0), 8, 2.5])       // pivot bores through arms
      rotate([0,90,0]) cylinder(d=pivot_hole, h=lever_arm_t+2, center=true);
    keyhole_slot();
  }
  if (hinge=="pip") for (s=[-1,1]) translate([s*(lever_w/2 - lever_arm_t/2), 8, 2.5])
    rotate([0,90,0]) cylinder(d=pivot_d, h=lever_arm_t+2*pip_gap+2, center=true); // integral pins
}
module cam_block() {
  // underside ramp: z drops cam_lift over 24mm of travel, then rises 0.15 for over-center
  translate([-lever_w/2, 20, 0]) rotate([90,0,90]) linear_extrude(lever_w)
    polygon([[0,0],[24,0],[24,-cam_lift],[26,-cam_lift+0.15],[27,-cam_lift+0.15],[27,3],[0,3]]);
}
module keyhole_slot() {
  translate([0, 32, -0.5]) union() {
    translate([-(stem_d+0.7)/2, 0, 0]) cube([stem_d+0.7, 14, 6]);   // stem travel slot
    translate([0, 14, 0]) cylinder(d=head_d+0.6, h=6);              // head insertion hole
  }
}
module snap_pin() {  // Ø matches boss free-fit, lever press-fit
  cylinder(d=pivot_d - 0.02, h=lever_w + 4);
  cylinder(d=pivot_d + 2, h=1.2);  // head
}
if (PART=="lever") lever();
if (PART=="pin") snap_pin();
```

- [ ] **Step 3: Write `scad/full_lid.scad`**

```openscad
include <params.scad>
use <lid.scad>
use <mech.scad>
HINGE = "pin";
$fn = 128;
module bosses() for (s=[-1,1]) translate([s*(lever_w/2 + 2), -flange_d/2 + 12, 0])
  difference() {
    cube([4, 10, 12], center=true);
    rotate([0,90,0]) cylinder(d=pivot_d + (HINGE=="pin" ? 0.3 : 0), h=6, center=true);
  }
difference() {
  union() { lid_body(variant="G", spout=true); bosses_on_flange(); }
  translate([0, flange_d/2 - 8, lid_top_z()]) sphere(r=detent_r + 0.15);  // detent pocket
}
module bosses_on_flange() translate([0, 0, lid_top_z() + 6]) bosses();
function lid_top_z() = thread_len + max(gland_w+3, lip_h+lip_gap+3) + flange_th;
if (HINGE=="pip") translate([0, -flange_d/2 + 12, lid_top_z() + 6]) rotate([-75,0,0]) lever("pip");
echo(str("FULLLID_OK hinge=", HINGE));
```

- [ ] **Step 4: Write `scad/assembly.scad`**

```openscad
include <params.scad>
use <lid.scad>
use <mech.scad>
SCENE = "closed";
$fn = 96;
module scene_closed() {
  color("SteelBlue") difference() { lid_body(variant="G", spout=true);
    translate([-200,0,-1]) cube(400); }             // cutaway half
  color("Orange") translate([0, bore_d/4, thread_len + gland_w + 3 + flange_th])
    plug();
}
module scene_open() { color("SteelBlue") lid_body(variant="G", spout=true);
  color("Orange") translate([0, bore_d/4, 40]) plug();
  color("Tomato") translate([0, -flange_d/2 + 12, 45]) rotate([-75,0,0]) lever(); }
if (SCENE=="closed") scene_closed();
if (SCENE=="open") scene_open();
echo(str("ASM_OK ", SCENE));
```

- [ ] **Step 5: Green.** Run: `make check && make renders stl`
Expected: all echoes OK; gallery now shows lever, pin, both full lids, and two scenes. Visual checks: cam ramp on lever underside; keyhole over the stem position; bosses aligned with lever pivot bores (this alignment is the step most likely to need a translate fix — adjust `bosses_on_flange`/lever local origins until the closed scene lines up).

- [ ] **Step 6: Commit**

```bash
git add scad/mech.scad scad/full_lid.scad scad/assembly.scad Makefile renders stl && git commit -m "feat: snap lever, both hinge builds, detent, assembly scenes"
```

### Task 17: PRINT GATE — Phase 3 full lid

**Files:**
- Modify: `prints.md`, `scad/params.scad` (mech tuning loop: `cam_lift`, `overcenter_deg`, `pip_gap`)

- [ ] **Step 1 (Blaine): print `full-lid-pin` + `lever` + `pin` + `plug` (PETG; plug/seat at 0.12mm). Assemble: head through keyhole, pin through bosses.**
- [ ] **Step 2 (Blaine): action test — snap closed (audible detent), snap open one-handed. Then full spec protocol: criteria 1–5 including 200 cycles.**
- [ ] **Step 3: Tune loop as needed (one parameter per print; log every attempt in `prints.md`). Try `full-lid-pip` once the pin build passes. Commit each iteration.**

### Task 18: Phase 4 soak, README finale, publish

**Files:**
- Modify: `README.md` (status → working; add gallery images + print settings table), `prints.md`

- [ ] **Step 1 (Blaine): one work week daily-driver soak; log regressions (creep, detent fade, seal weep).**
- [ ] **Step 2: README: replace status line, embed 2–3 renders + a real photo, document final print settings and assembly steps; note Variant L verdict honestly.**
- [ ] **Step 3: Tag + push:**

```bash
git add README.md prints.md && git commit -m "docs: v1.0 — daily-driver validated" && git tag v1.0 && git push && git push --tags
```

---

## Self-review notes (run after drafting — resolved)

- Spec coverage: §1→Tasks 12/13/17 gates; §2.1→3/7/9/10/11; §2.2→11/12/13; §2.3→14/15/16/17; §3→4/5/6/9; §4→print-gate settings lines; §5 ladder→Tasks 9–17 in order; §6 mitigations→tuning loops in 12/13/14/17; §7→Tasks 1/8 + repo layout. No gaps found.
- Known-fragile steps are labeled where visual verification is the test (slot-card edge cuts, boss/lever alignment) — renders are the red/green signal there.
- Type consistency: all cross-file names come from `params.scad` (Task 3 list) — `seat_sleeve_local` in mech vs `seat_sleeve` in lid intentionally duplicated (coupon must not depend on lid.scad); flagged as acceptable DRY exception.

## Execution deviations (2026-07-07, Tasks 1–8)

Recorded during inline execution; the committed code is the source of truth.

1. Makefile: directory creation moved into recipes (`mkdir -p $(@D)`) — the planned `build renders stl:` rule collided with the phony `renders` aggregate target.
2. Makefile: the check recipe greps the `.echo` output for ERROR/WARNING and deletes it on failure — OpenSCAD 2021.01 exits 0 when an assert fails during `.echo` export, so exit codes alone are green-blind.
3. Makefile: gallery invocation guarded with `[ -x tools/gallery.sh ]` so Task 4–7 renders don't fail before Task 8 creates the script.
4. gauges.scad: step-cone retrieval bore removed (the grip bar makes it redundant, and the bore split the bar); grip bar embedded 1mm into the top step.
5. gauges.scad: slot-card layout rewritten with cumulative-sum functions (`sumv`/`slot_x`/`row_w`) instead of the plan's draft recursion; two opposing rows, vertical labels, `H = 2*depth + 22`.
6. params.scad: `gland_w` factor raised 1.18 → 1.30 — the gland-fill assert caught the planned value overfilling the groove (0.95 > 0.92 cap); fill ≈ 0.87 and is independent of the measured cross-section.
7. ring.scad: `thread_depth` passed explicitly to `trapezoidal_threaded_rod` (BOSL2's default of pitch/2 silently overrode the params value).
8. CGAL reading note: `Volumes: 2` in STL export stats = one solid + the unbounded outer cell. A single printable part reports 2, not 1.

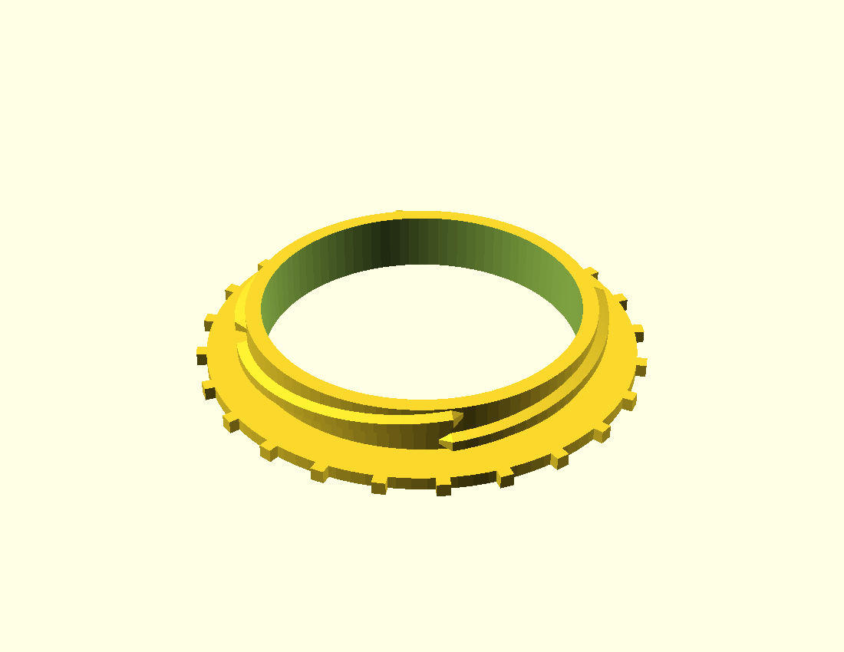
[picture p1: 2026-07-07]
renders/ring-c15.png

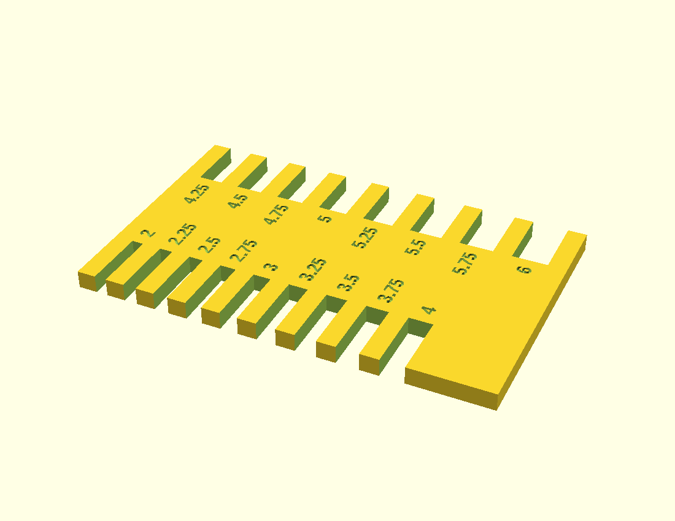
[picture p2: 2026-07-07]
renders/gauge-slotcard.png

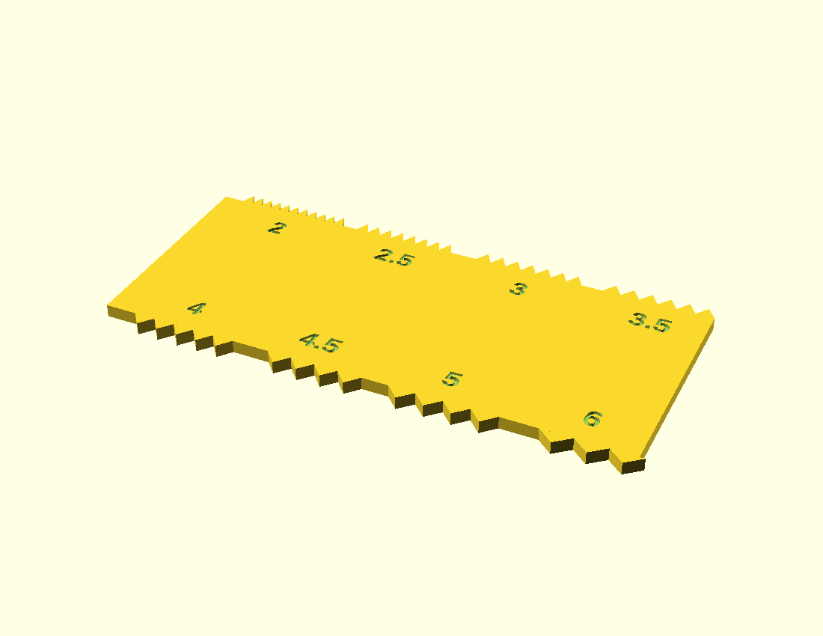
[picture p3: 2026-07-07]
renders/gauge-comb.png

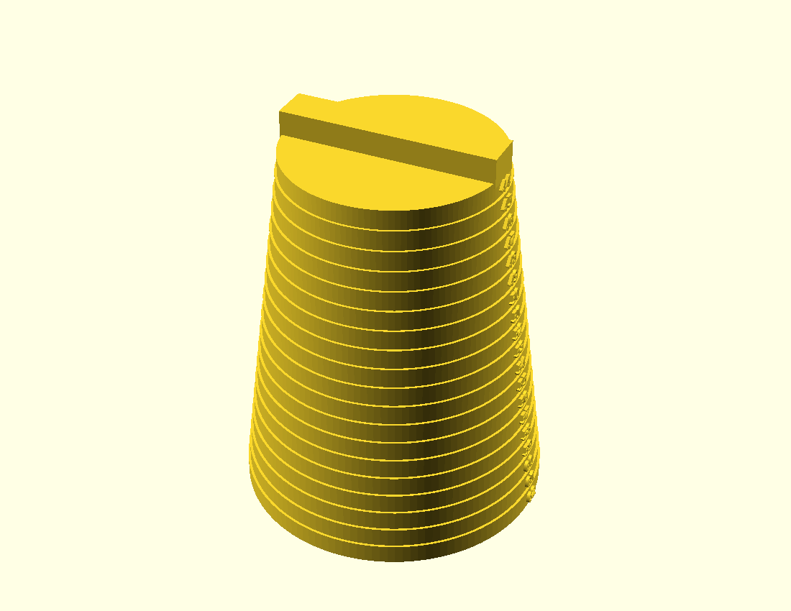
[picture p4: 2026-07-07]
renders/gauge-cone.png

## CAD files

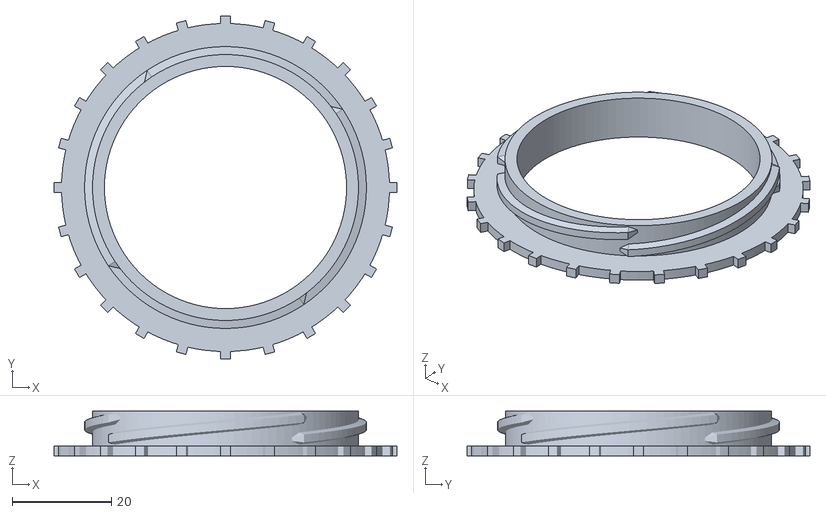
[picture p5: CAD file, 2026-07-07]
stl/ring-c15.stl
69.0 x 69.0 x 9.00

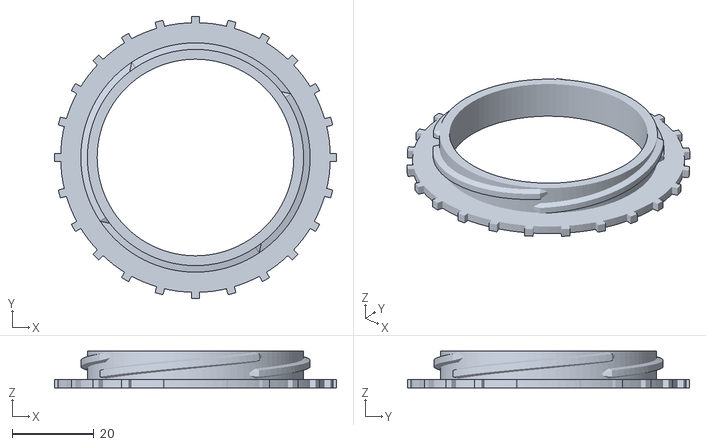
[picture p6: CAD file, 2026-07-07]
stl/ring-c45.stl
69.0 x 69.0 x 9.00

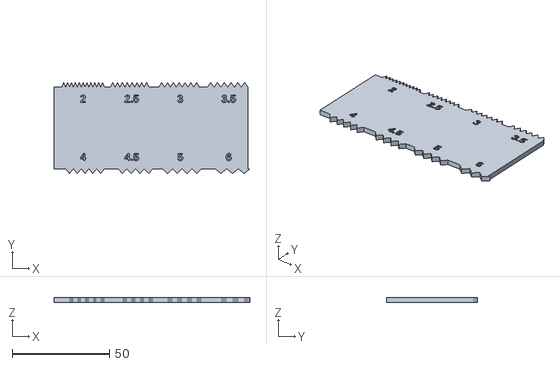
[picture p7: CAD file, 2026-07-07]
stl/gauge-comb.stl
101.0 x 47.0 x 2.40

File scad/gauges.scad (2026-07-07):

// gauges.scad — printed metrology (PLA fine: never touches heat)
include <params.scad>
PART = "all";
$fn = 128;
FONT = "Liberation Sans:style=Bold";

// Step cone: largest step on bed, stack shrinks upward => no overhang.
// In use: flip tip-down into mug mouth; the step that rests on the rim = bore Ø.
module step_cone_gauge(d_min=44, d_max=62, step=1, h_step=4) {
  n = floor((d_max - d_min)/step);
  union() {
    for (i=[0:n]) {
      d = d_max - i*step;
      translate([0,0,i*h_step]) cylinder(d=d, h=h_step+0.02);
      translate([0,0,i*h_step + h_step/2]) label_on_wall(d, str(d));
    }
    translate([0,0,(n+1)*h_step - 1]) grip_bar(d_max - n*step); // embedded 1mm into top step
  }
}
// Embossed label standing 0.6mm proud of the step wall, reading upright.
module label_on_wall(d, txt)
  translate([d/2 - 0.1, 0, 0]) rotate([90,0,90])
    linear_extrude(0.7) text(txt, size=2.6, font=FONT, halign="center", valign="center");
module grip_bar(d_top)
  translate([-d_top/2, -4, 0]) cube([d_top, 8, 6]);

// Pitch comb: hold a comb edge against the neck threads; the tooth set
// that nests into the crests IS the pitch. 4 candidates per long edge.
module pitch_comb(pitches=[2,2.5,3,3.5,4,4.5,5,6], seg=22, card=[100,42,2.4]) {
  difference() {
    union() {
      cube(card);
      for (i=[0:3]) comb_edge(pitches[i],   seg, [4 + i*(seg+3), card[1], 0], 0);   // top edge
      for (i=[0:3]) comb_edge(pitches[i+4], seg, [4 + i*(seg+3) + seg, 0, 0], 180); // bottom edge
    }
    for (i=[0:3]) comb_label(pitches[i],   [4 + i*(seg+3) + seg/2, card[1]-6], card[2]);
    for (i=[0:3]) comb_label(pitches[i+4], [4 + i*(seg+3) + seg/2, 6],         card[2]);
  }
}
module comb_edge(p, seg, at, rot) translate(at) rotate([0,0,rot]) {
  n = floor(seg/p);
  for (t=[0:n-1]) translate([t*p, 0, 0])
    linear_extrude(2.4) polygon([[0,0],[p/2,2.5],[p,0]]);  // 2.5mm-deep V teeth at pitch p
}
module comb_label(p, at, th) translate([at[0], at[1], th-0.6])
  linear_extrude(0.7) text(str(p), size=4, font=FONT, halign="center", valign="center");

// Slot card: slide the grommet cross-section into slots until snug — the snug
// slot IS the dimension. Soft rubber measures badly under a ruler, well in a slot.
function sumv(v, n) = n<=0 ? 0 : v[n-1] + sumv(v, n-1);
function slot_x(ws, i, wall) = wall + sumv(ws, i) + i*wall;
function row_w(ws, wall) = wall + sumv(ws, len(ws)) + len(ws)*wall;

module slot_card(depth=11, th=3.0, wall=3.2) {
  row1 = [for (w=[2.0:0.25:4.0]) w];    // bottom edge
  row2 = [for (w=[4.25:0.25:6.0]) w];   // top edge
  H = 2*depth + 22;
  W = max(row_w(row1, wall), row_w(row2, wall));
  difference() {
    cube([W, H, th]);
    for (i=[0:len(row1)-1]) {
      x = slot_x(row1, i, wall);
      translate([x, -0.5, -0.5]) cube([row1[i], depth+0.5, th+1]);
      slot_label(row1[i], x + row1[i]/2, depth+2, "left", th);
    }
    for (i=[0:len(row2)-1]) {
      x = slot_x(row2, i, wall);
      translate([x, H-depth, -0.5]) cube([row2[i], depth+0.5, th+1]);
      slot_label(row2[i], x + row2[i]/2, H-depth-2, "right", th);
    }
  }
}
// vertical (rotated) debossed label so it fits above narrow slots
module slot_label(w, x, y, hal, th) translate([x, y, th-0.6])
  linear_extrude(0.7) rotate([0,0,90])
    text(str(w), size=2.4, font=FONT, halign=hal, valign="center");

if (PART=="cone" || PART=="all") step_cone_gauge();
if (PART=="comb" || PART=="all") translate([90,0,0]) pitch_comb();
if (PART=="slotcard" || PART=="all") translate([0,-90,0]) slot_card();
echo("GAUGES_OK");

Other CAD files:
stl/ring-c30.stl
scad/params.scad
scad/ring.scad
scad/smoke.scad

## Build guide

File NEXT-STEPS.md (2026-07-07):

# NEXT STEPS — start here when picking this project back up

**Status (2026-07-07):** Plan tasks 1–8 done. The build system, measuring kit, and thread
test rings exist and are committed. **Nothing can proceed until the measurements below
happen** — that's you + your printer, ~30 minutes. After that, an LLM takes it from Task 9.

## Part 1 — You (human, ~30 min)

1. **Print the measuring kit** from `stl/` (PLA fine, draft 0.28mm, no supports):
   - `gauge-cone.stl` — flip tip-down into the mug mouth. The labeled step that rests
     on the rim **is** the bore diameter.
   - `gauge-comb.stl` — hold comb edges against the neck threads. The tooth set that
     nests into the crests **is** the pitch.
   - `gauge-slotcard.stl` — slide the grommet's cross-section into slots until snug,
     once for its radial thickness, once for its axial height.
2. **Take photos** into `docs/photos/` (ruler in frame where noted):
   1. Mug mouth, top-down, ruler across the diameter
   2. Neck threads, side close-up, ruler vertical
   3. Rim angle shot where the **thread entry points** can be counted
   4. Old lid: side profile
   5. Old lid: underside, grommet removed
   6. Old lid: mechanism open (side + from below)
   7. Grommet flat on the ruler
3. **Fill in `docs/photos/readings.txt`** (template is there — blank fields are OK,
   they get bracketed by test prints instead).

## Part 2 — LLM (paste this prompt)

> Continue the Byron Reborn project in this repo. Read, in order: `CLAUDE.md`,
> `docs/superpowers/specs/2026-07-07-byron-lid-design.md`, and
> `docs/superpowers/plans/2026-07-07-byron-reborn.md`, resuming at **Task 9**.
> New inputs: photos in `docs/photos/` and `docs/photos/readings.txt`.
> Task 9: update `scad/params.scad` — set measured values, flip `[PROVISIONAL]` tags to
> `[MEASURED 2026-MM-DD]`, confirm the thread male/female assumption from the photos,
> keep `make check` green, log in `prints.md`, commit.
> Task 10: `make stl`, then ask me to print `ring-c15/30/45.stl` in **PETG** and report
> which one spins smoothly and seats without wobble; freeze that clearance.
> Then follow the plan's remaining tasks in order. Hard rules: every dimension lives in
> `scad/params.scad` only; every part passes `make check` before STL export; commit after
> each green step; PETG for anything that touches heat or seals.

## Remaining roadmap (who does what)

| Task | What | Who |
|---|---|---|
| 9 | Measurements + photos → `params.scad` goes `[MEASURED]` | You measure, LLM edits |
| 10 | Print 3 thread rings, pick the fit, freeze clearance | You print/try, LLM freezes |
| 11 | Lid body core (threaded skirt, blank top) | LLM |
| 12 | Print blank lid + grommet, hot/invert/backpack leak tests | You |
| 13 | Printed-lip variant, same tests | LLM + you |
| 14 | Spout coupon: taper plug seal test (+ toothpaste lapping) | LLM + you |
| 15 | Screw-plug fallback cap | LLM |
| 16 | Snap lever, hinge (pin + print-in-place), assembly scenes | LLM |
| 17 | Full lid: assemble, 200-cycle + full leak protocol | You |
| 18 | Week-long daily-driver soak, README finale, tag v1.0 | You + LLM |

Design rationale (why grommet gland, why taper plug, why half-turn law): see the spec.
Previews of every part: `open renders/index.html` (regenerates via `make renders`).

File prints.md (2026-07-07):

# Print & Test Log — Byron Reborn

Toolchain: OpenSCAD version 2021.01 (Homebrew), Bambu Studio, Bambu Lab H2D, 0.4mm nozzle.

| Date | Part (stl @ commit) | Filament | Key settings | Result | Notes |
|---|---|---|---|---|---|

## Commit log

2026-07-07 Add Byron Reborn lid design spec
    Approved design for printed leak-proof Contigo Byron 2.0 replacement lid:
    parametric BOSL2 threads, grommet-gland + printed-lip seal variants,
    floating-plug snap lever, printed measuring kit, phased test ladder.
2026-07-07 plan: Byron Reborn implementation plan (18 tasks, print gates marked)
2026-07-07 build: scaffolding, Makefile part-template, print log
2026-07-07 build: BOSL2 submodule (fbcdfdd5) + thread smoke test
    [smoke.scad]
2026-07-07 feat: full parameter set with half-turn + gland-fill asserts
    Gland-fill assert caught the first provisional geometry overfilled at
    0.95; axial allowance widened to 1.30 (fill ~0.87). Also harden make
    check: OpenSCAD 2021.01 exits 0 on assert failure during .echo export,
    so the recipe now greps output for ERROR/WARNING.
    [params.scad, smoke.scad]
2026-07-07 feat: step-cone bore gauge (44-62mm, 1mm steps)
    Grip bar embedded 1mm; retrieval bore dropped (bar makes it redundant,
    and it split the bar). Note: CGAL 'Volumes: 2' = solid + outer cell,
    i.e. one printable part.
    [gauges.scad]
2026-07-07 feat: thread pitch comb (2-6mm, 8 candidates)
    [gauge-comb.stl, gauges.scad]
2026-07-07 feat: grommet slot gauge card (2-6mm x 0.25, two rows)
    [gauges.scad]
2026-07-07 feat: parametric thread test rings at 3 clearances
    thread_depth now passed explicitly (BOSL2 default pitch/2 silently
    overrode the params value).
    [ring-c15.stl, ring-c30.stl, ring-c45.stl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]
2026-07-07 docs: cold-pickup handoff — NEXT-STEPS, CLAUDE.md, readings template
